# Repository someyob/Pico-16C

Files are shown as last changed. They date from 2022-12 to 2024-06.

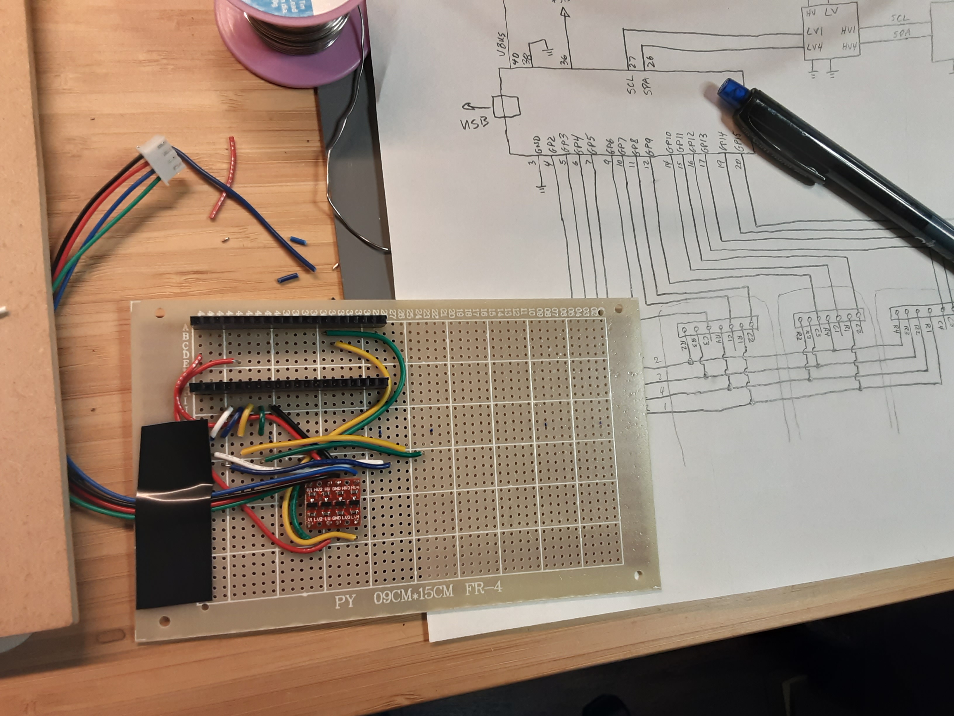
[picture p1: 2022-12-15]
pics/20221129_102227.jpg

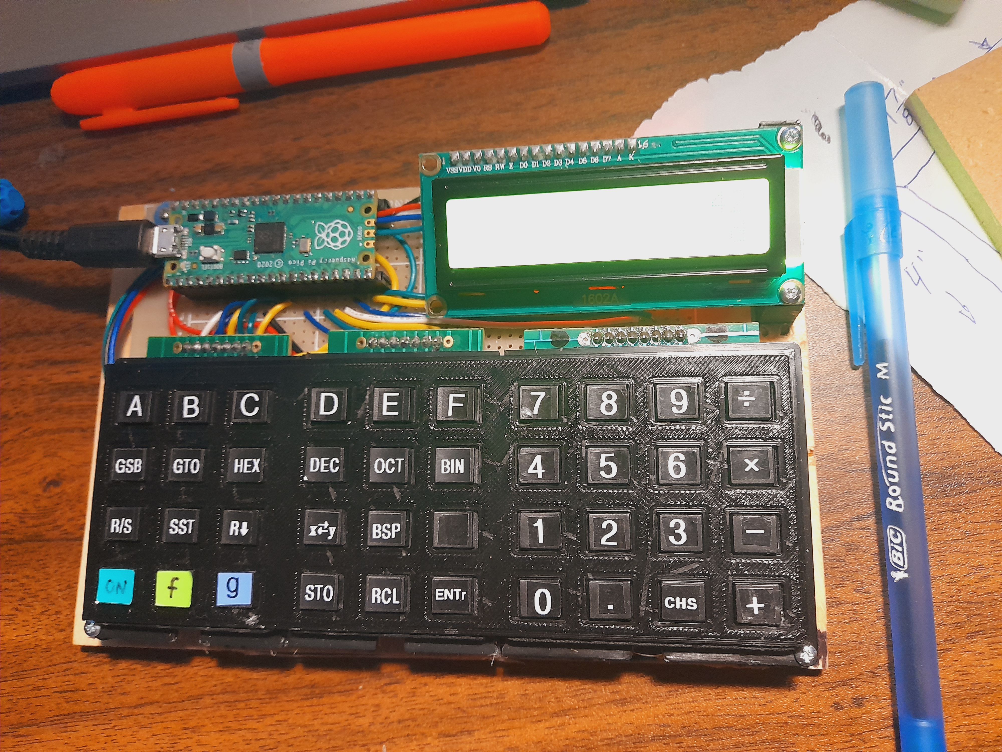
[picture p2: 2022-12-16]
pics/20221216_104609.jpg

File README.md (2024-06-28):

Hi there, while you're here, maybe check out the newer version of this project:
https://github.com/someyob/Pico16cV2

# Pico-16C

Notes for new version 0.5:
  - added floating point entry and operations.  Note that CicruitPython only uses single precision floats, so some results will seem unexpected.  < examples follow >  I may restrict the number of decimal places (for example, entering float mode by pressing f-FLOAT-{0..9,.}, where 0 to 9 represents the number of decimal points you want to work with) to 5, even though that doesn't really mitigate the issue.  Best option would be for CircuitPython to match what Python 3 is able to handle double precision floats.  Not going to get hung up on it, as I would typically not frequently use the calculator for floating point calculations.
  - Differences between Pico16C 0.5 and the HP 16C:
      - switching from an integer base to floating point will convert what's in the X register, but the opposite is not true.  Further, the conversion from integer to float simply changes the representation, not the number.  The stack is unchanged, and the word size is ignored.
      - added a 'hidden function' to allow for a 'thousands separator' (eg. 64,636) to make readability better for long numbers.  Unfortunately, separators do not work for binary and hex representations (eg. 1100 1100 0001, or FFEH AE12) due to a bug in CicruitPython as of version 8)

Wanted an HP 16C calculator, the gold standard for early programmers.  Didn't have one, too cheap to buy one off eBay, and while the new ones you can get from SwissMicro https://www.swissmicros.com/product/dm16l look great, they don't scratch my other itch, which is to play with microcontrollers and learn a new language (python).



Python is well suited to this application given a full suite of excellent string manipulation and math libraries, adafruit libraries, etc.  Execution speed is not an issue.

I was helped a lot during development with access to a couple of different software emulators out there (http://www.hp16c.org/ and https://stendec.io/ctb/rpn_prog.html), especially when I can see what's happening with the stack.  The manual https://literature.hpcalc.org/community/hp16c-oh-en.pdf was also essential reading.

An early version of this project got a mention on the Raspberry Pi blog https://www.raspberrypi.com/news/replica-hp-16c-coding-calculator/ and on Adafruit's Python on Hardware newsletter https://blog.adafruit.com/2022/10/19/icymi-python-on-microcontrollers-newsletter-ladyada-at-espressif-devcon-this-week-circuitpython-8-beta-2-and-more-circuitpython-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

display

Tools and materials used:
  - Raspberry Pi Pico
  - 1602 LCD display (w. i2c backpack)
  - breadboards and soldering iron
  - perfboard, w. 22awg wire
  - level shifter module (only using 2 out of 4 lines for i2c)
  - two 3x4 and one 4x4 aliexpress keypads (modified to jam as close together as possible)
  - 3d Printer
  - Glue gun
  - PTouch Labelmaker
  - Laser printer (for keypad overlay), highlighter pens
  - Thonny with Circuitpython 7.2.3
  
The software emulates (mimics) the basic operations of a 16C, all in Reverse Polish Notation (RPN) with the standard X, Y, Z and T registers.
What it's currently capable of:
  - integer entry in either hexadecimal, octal, decimal or binary
  - conversions between those bases
  - ordinary arithmatic (+ - / *), some bitwise operations (NOT, AND, etc)
  - stack operations x<->y, R^, Rv, LastX
  
Differences between this and a real 16C:
  - maximum 128 bit words (vs 16C 64 bit)
  - 16 character display, with eight 16 character windows, scrolling with shift-g < and > keys
  - 'Enter' key is standard size, not double lenth like a real 16C
  - Has a splash screen that gives you the current version number
  - Has a timeout feature that turns off the LCD after 5 minutes (hard coded)
  - The calculator is always 'running', ON and OFF simply turns off the display and backlight

Work to come in the near future:
  - floating point
  - more bitwise operations, 1's and 2's complement arithmetic

Work to come in the far future (if ever):
  - Programming mode

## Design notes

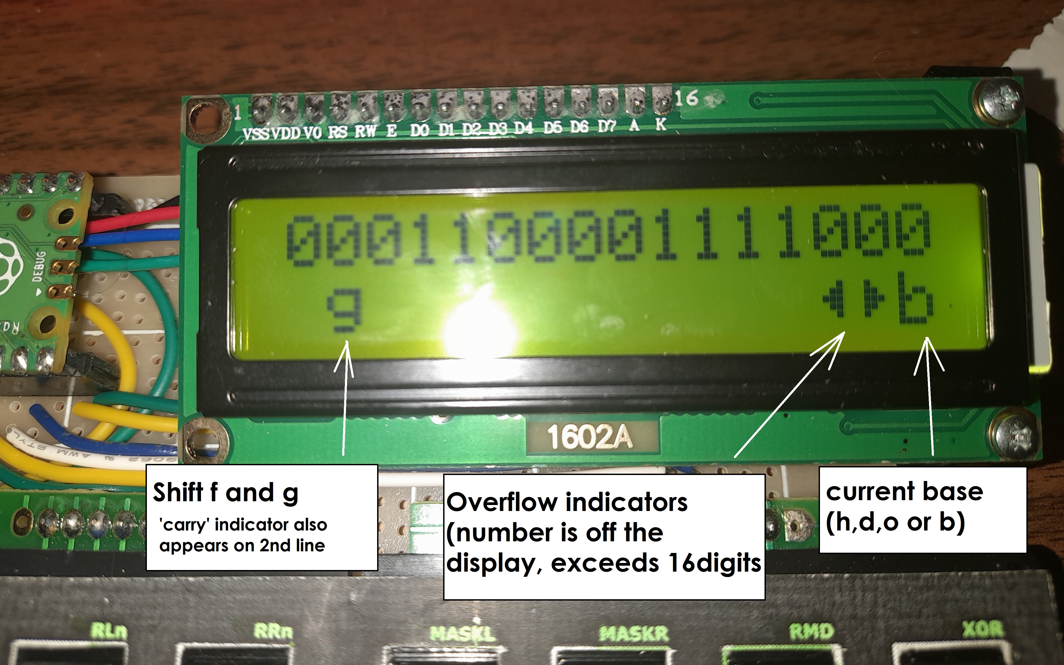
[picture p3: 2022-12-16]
pics/display.jpg

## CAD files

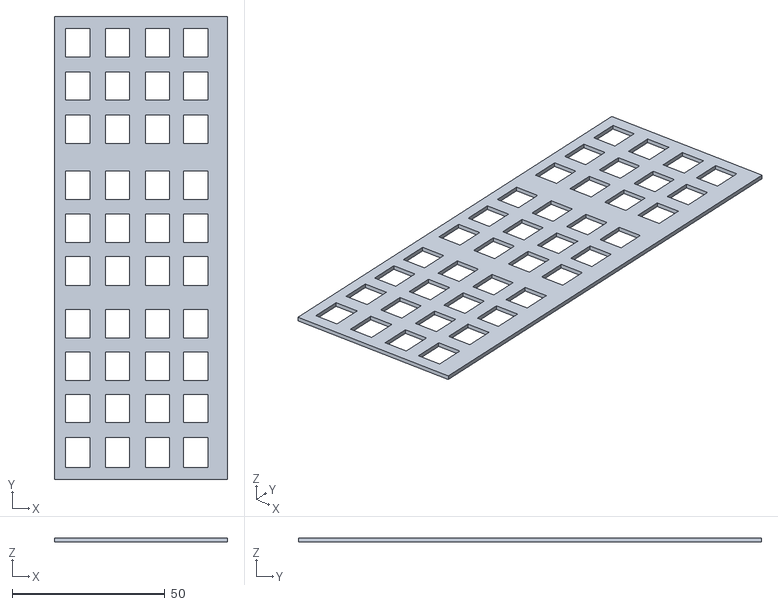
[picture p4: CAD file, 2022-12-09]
hardware/faceplate.stl
56.8 x 151.8 x 1.25

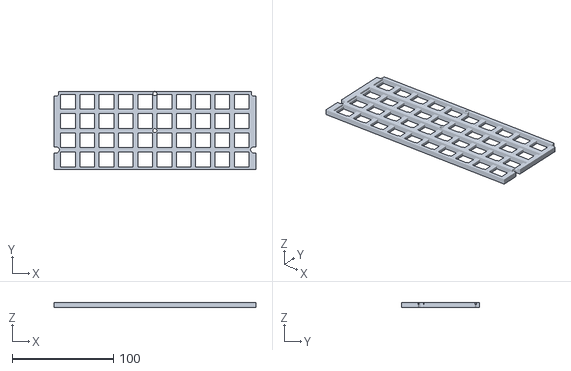
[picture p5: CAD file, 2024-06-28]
v2/3dprints/keypad.stl
199.9 x 77.6 x 4.80

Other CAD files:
hardware/faceplate.skp
hardware/spacer.skp
v2/3dprints/keypad.skp

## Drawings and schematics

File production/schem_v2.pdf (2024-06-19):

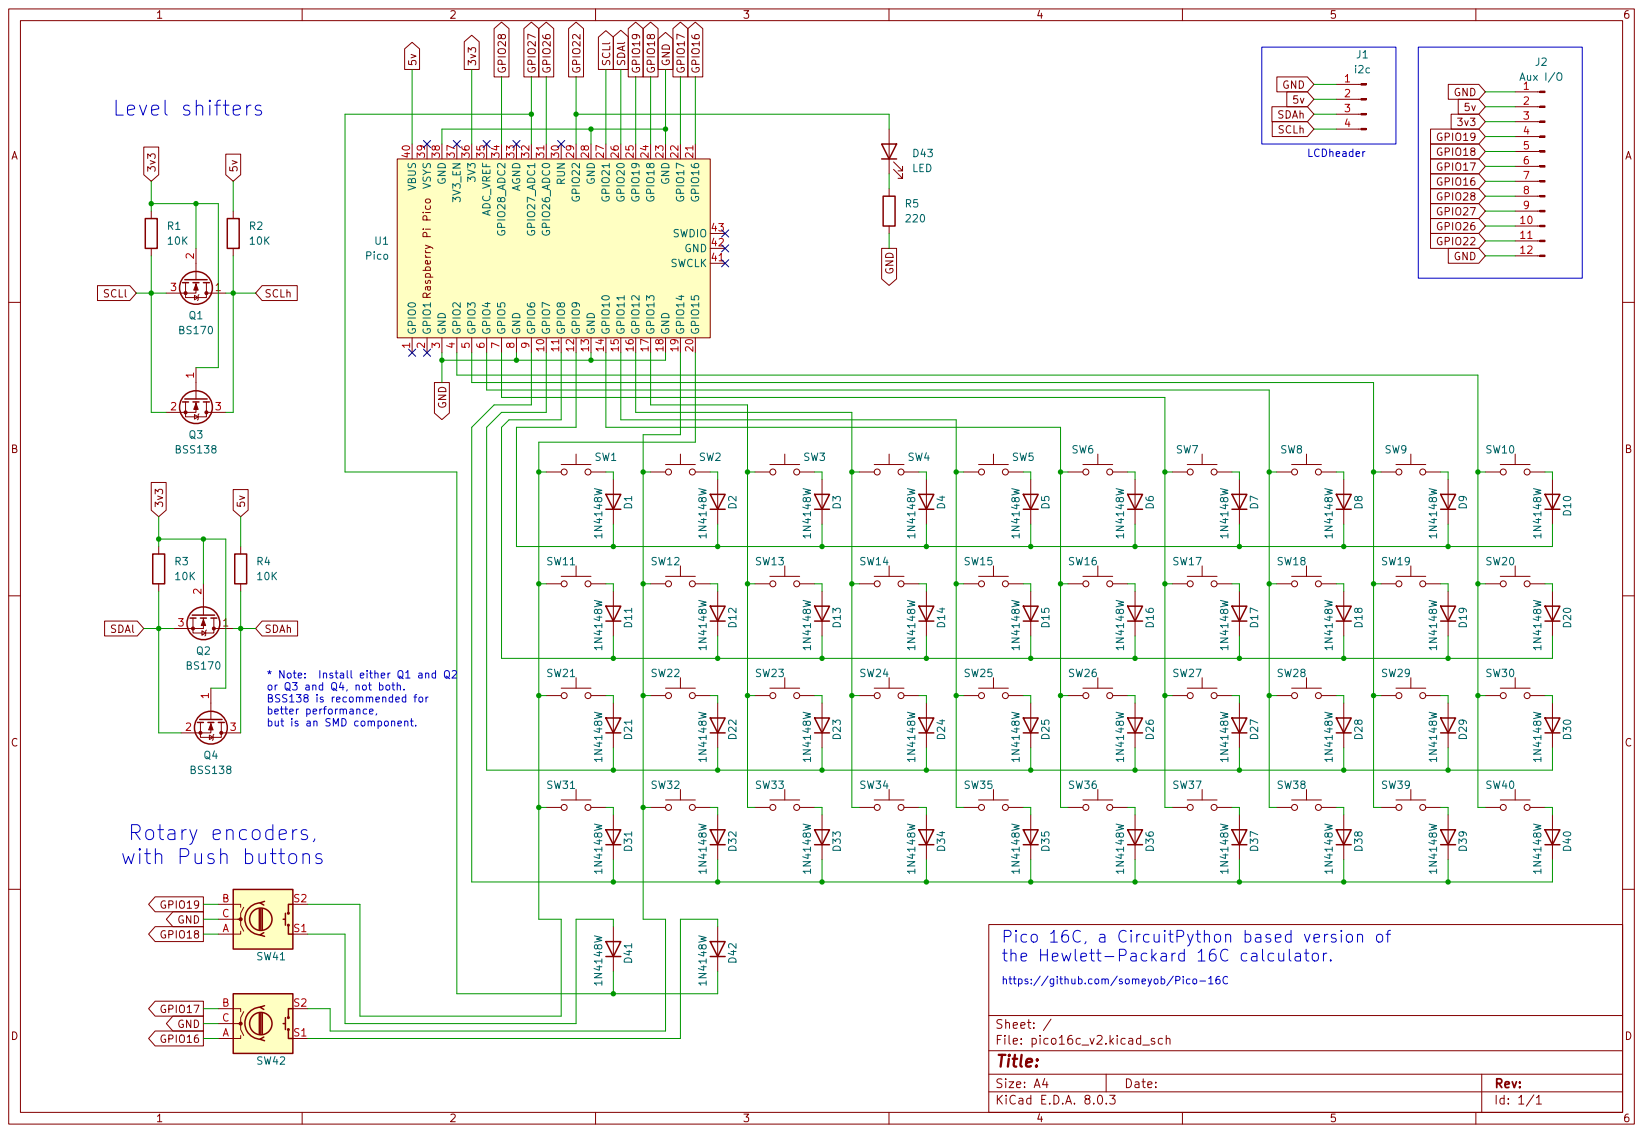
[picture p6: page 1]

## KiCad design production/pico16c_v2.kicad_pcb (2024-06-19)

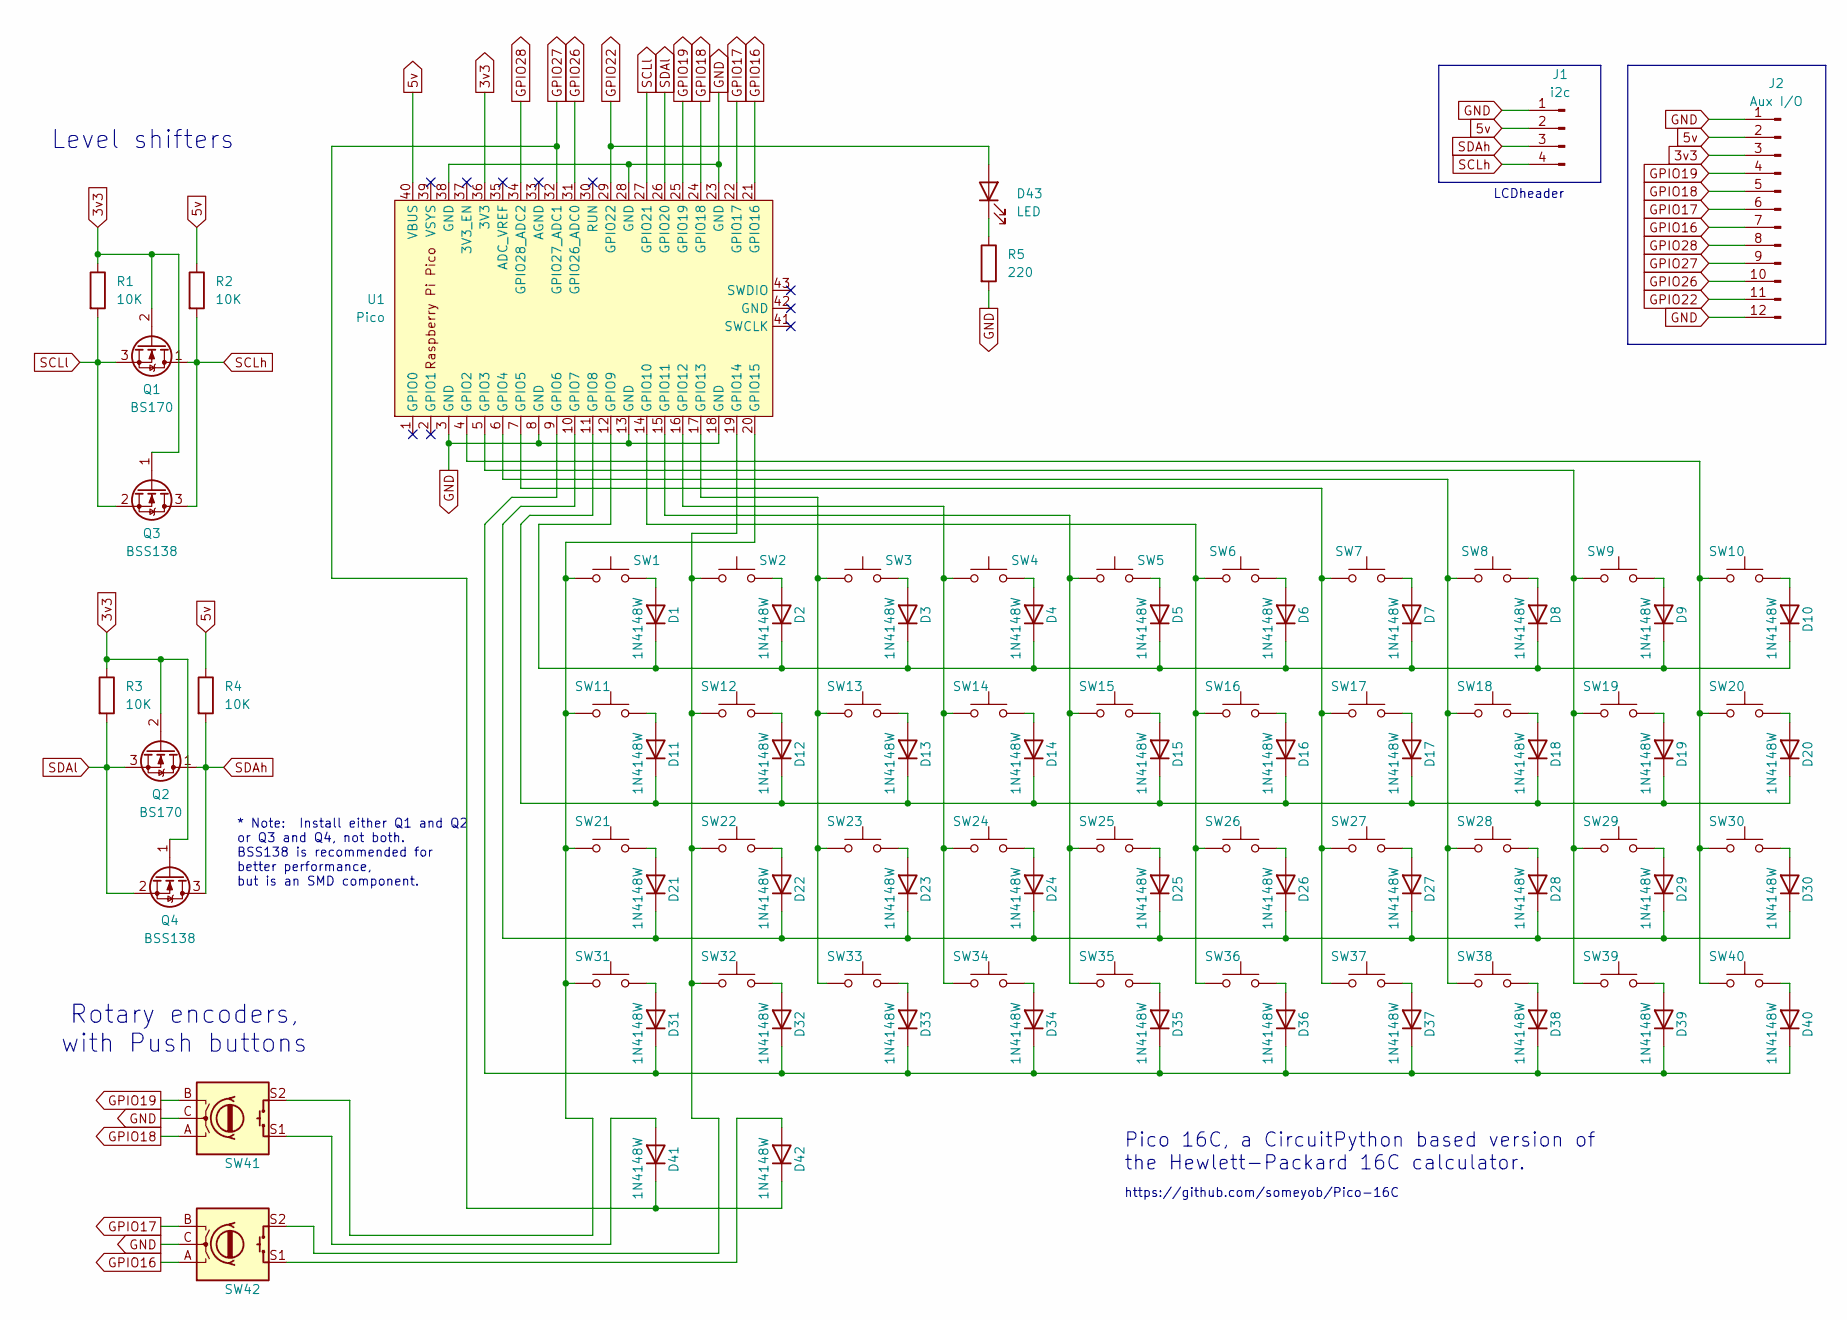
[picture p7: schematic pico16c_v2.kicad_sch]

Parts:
D1, D2, D3, D4, D5, D6, D7, D8, D9, D10, D11, D12, D13, D14, D15, D16, D17, D18, D19, D20, D21, D22, D23, D24, D25, D26, D27, D28, D29, D30, D31, D32, D33, D34, D35, D36, D37, D38, D39, D40, D41, D42: 1N4148W; D_DO-35_SOD27_P7.62mm_Horizontal
D43: LED; LED_D2.0mm_W4.0mm_H2.8mm_FlatTop
J1: i2c; PinHeader_1x04_P2.54mm_Vertical
J2: Aux I/O; PinHeader_1x12_P2.54mm_Vertical
Q1, Q2: BS170; TO-92_Inline
Q3, Q4: BSS138; SOT-23
R1, R2, R3, R4: 10K; R_Axial_DIN0207_L6.3mm_D2.5mm_P10.16mm_Horizontal
R5: 220; R_Axial_DIN0207_L6.3mm_D2.5mm_P10.16mm_Horizontal
SW1, SW2, SW3, SW4, SW5, SW6, SW7, SW8, SW9, SW10, SW11, SW12, SW13, SW14, SW15, SW16, SW17, SW18, SW19, SW20, SW21, SW22, SW23, SW24, SW25, SW26, SW27, SW28, SW29, SW30, SW31, SW32, SW33, SW34, SW35, SW36, SW37, SW38, SW39, SW40: SW_Push; SW_Cherry_MX_1.00u_PCB
SW41, SW42: Encoder_Switch; RotaryEncoder_Alps_EC11E-Switch_Vertical_H20mm
U1: Pico; RPi_Pico_SMD_TH

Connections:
3v3: J2.3, Q1.2 (G), Q2.2 (G), Q3.1 (G), Q4.1 (G), R1.1, R3.1, U1.36 (3V3)
5v: J1.2, J2.2, R2.1, R4.1, U1.40 (VBUS)
GND: J1.1, J2.1, J2.12, R5.2, SW41.C, SW42.C, U1.3 (GND), U1.8 (GND), U1.13 (GND), U1.18 (GND), U1.23 (GND), U1.28 (GND), U1.38 (GND)
GPIO16: J2.7, SW42.A, U1.21 (GPIO16)
GPIO17: J2.6, SW42.B, U1.22 (GPIO17)
GPIO18: J2.5, SW41.A, U1.24 (GPIO18)
GPIO19: J2.4, SW41.B, U1.25 (GPIO19)
GPIO22: D43.2 (A), J2.11, U1.29 (GPIO22)
GPIO26: J2.10, U1.31 (GPIO26_ADC0)
GPIO27: D41.1 (K), D42.1 (K), J2.9, U1.32 (GPIO27_ADC1)
GPIO28: J2.8, U1.34 (GPIO28_ADC2)
unnamed: D1.2 (A), SW1.1
unnamed: D1.1 (K), D2.1 (K), D3.1 (K), D4.1 (K), D5.1 (K), D6.1 (K), D7.1 (K), D8.1 (K), D9.1 (K), D10.1 (K), U1.12 (GPIO9)
unnamed: D2.2 (A), SW2.1
unnamed: D3.2 (A), SW3.1
unnamed: D4.2 (A), SW4.1
unnamed: D5.2 (A), SW5.1
unnamed: D6.2 (A), SW6.1
unnamed: D7.2 (A), SW7.1
unnamed: D8.2 (A), SW8.1
unnamed: D9.2 (A), SW9.1
unnamed: D10.2 (A), SW10.1
unnamed: D11.2 (A), SW11.1
unnamed: D11.1 (K), D12.1 (K), D13.1 (K), D14.1 (K), D15.1 (K), D16.1 (K), D17.1 (K), D18.1 (K), D19.1 (K), D20.1 (K), U1.11 (GPIO8)
unnamed: D12.2 (A), SW12.1
unnamed: D13.2 (A), SW13.1
unnamed: D14.2 (A), SW14.1
unnamed: D15.2 (A), SW15.1
unnamed: D16.2 (A), SW16.1
unnamed: D17.2 (A), SW17.1
unnamed: D18.2 (A), SW18.1
unnamed: D19.2 (A), SW19.1
unnamed: D20.2 (A), SW20.1
unnamed: D21.2 (A), SW21.1
unnamed: D21.1 (K), D22.1 (K), D23.1 (K), D24.1 (K), D25.1 (K), D26.1 (K), D27.1 (K), D28.1 (K), D29.1 (K), D30.1 (K), U1.10 (GPIO7)
unnamed: D22.2 (A), SW22.1
unnamed: D23.2 (A), SW23.1
unnamed: D24.2 (A), SW24.1
unnamed: D25.2 (A), SW25.1
unnamed: D26.2 (A), SW26.1
unnamed: D27.2 (A), SW27.1
unnamed: D28.2 (A), SW28.1
unnamed: D29.2 (A), SW29.1
unnamed: D30.2 (A), SW30.1
unnamed: D31.2 (A), SW31.1
unnamed: D31.1 (K), D32.1 (K), D33.1 (K), D34.1 (K), D35.1 (K), D36.1 (K), D37.1 (K), D38.1 (K), D39.1 (K), D40.1 (K), U1.9 (GPIO6)
unnamed: D32.2 (A), SW32.1
unnamed: D33.2 (A), SW33.1
unnamed: D34.2 (A), SW34.1
unnamed: D35.2 (A), SW35.1
unnamed: D36.2 (A), SW36.1
unnamed: D37.2 (A), SW37.1
unnamed: D38.2 (A), SW38.1
unnamed: D39.2 (A), SW39.1
unnamed: D40.2 (A), SW40.1
unnamed: D41.2 (A), SW41.S1
unnamed: D42.2 (A), SW42.S1
unnamed: D43.1 (K), R5.1
unnamed: SW10.2, SW20.2, SW30.2, SW40.2, U1.4 (GPIO2)
unnamed: SW9.2, SW19.2, SW29.2, SW39.2, U1.5 (GPIO3)
unnamed: SW8.2, SW18.2, SW28.2, SW38.2, U1.6 (GPIO4)
unnamed: SW7.2, SW17.2, SW27.2, SW37.2, U1.7 (GPIO5)
unnamed: SW6.2, SW16.2, SW26.2, SW36.2, U1.14 (GPIO10)
unnamed: SW5.2, SW15.2, SW25.2, SW35.2, U1.15 (GPIO11)
unnamed: SW4.2, SW14.2, SW24.2, SW34.2, U1.16 (GPIO12)
unnamed: SW3.2, SW13.2, SW23.2, SW33.2, U1.17 (GPIO13)
unnamed: SW2.2, SW12.2, SW22.2, SW32.2, SW42.S2, U1.19 (GPIO14)
unnamed: SW1.2, SW11.2, SW21.2, SW31.2, SW41.S2, U1.20 (GPIO15)
SCLh: J1.4, Q1.1 (D), Q3.3 (D), R2.2
SCLl: Q1.3 (S), Q3.2 (S), R1.2, U1.27 (GPIO21)
SDAh: J1.3, Q2.1 (D), Q4.3 (D), R4.2
SDAl: Q2.3 (S), Q4.2 (S), R3.2, U1.26 (GPIO20)

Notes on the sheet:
Pico 16C, a CircuitPython based version of the Hewlett-Packard 16C calculator.
https://github.com/someyob/Pico-16C
LCDheader
* Note: Install either Q1 and Q2 or Q3 and Q4, not both. BSS138 is recommended for better performance, but is an SMD component.
Rotary encoders, with Push buttons
Level shifters

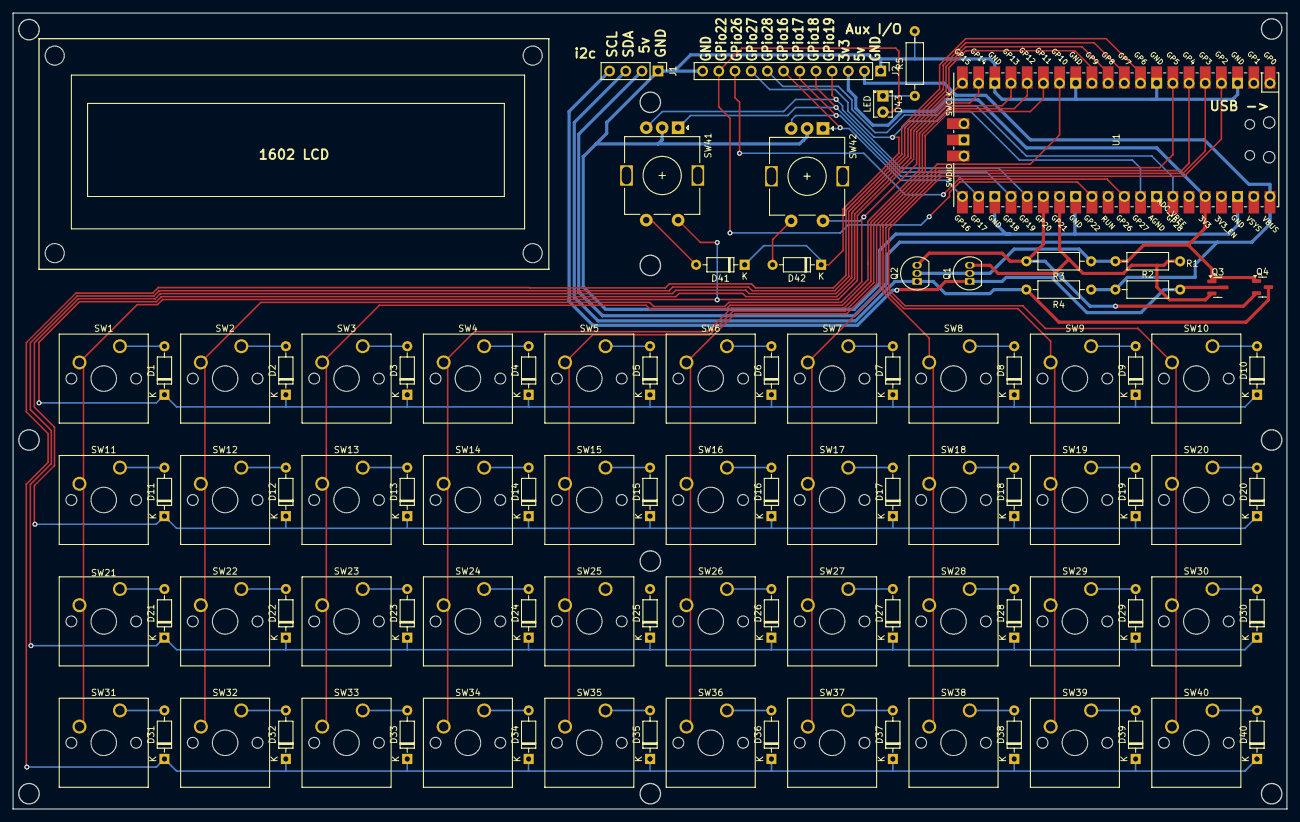
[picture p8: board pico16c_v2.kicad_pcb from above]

Board: 2 copper layers, 199.9 x 124.9 mm, 97 parts (0 on the bottom side), 72 nets.

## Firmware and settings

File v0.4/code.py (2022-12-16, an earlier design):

# to do:
# CLEAR PRGM
# CLEAR REG
# CLEAR PREFIX

import gc
import time
import board
import busio
from time import sleep, monotonic
from circuitpython_i2c_lcd import I2cLcd
from PICO_16C_keypad import *


version_string = "Pico 16C v0.4"
release_string = "13 Dec 2022"

import keypad


i2c = busio.I2C(board.GP21, board.GP20)   # SCL, SDA
# circuitpython seems to require locking the i2c bus
while i2c.try_lock():
    pass

DEFAULT_I2C_ADDR = 0x27
lcd = I2cLcd(i2c, DEFAULT_I2C_ADDR, 2, 16)

def splash():
    lcd.backlight_on()
    print(version_string)
    print(release_string)
    lcd.clear()
    lcd.putstr(version_string)
    lcd.move_to(0, 1)
    lcd.putstr(release_string)
    sleep(3)
    return

base_char = [ 'b', 'o', 'd', 'h' ]
shift_char = [' ', 'f', 'g']
float_str = 'float'
arrow_overflow_right = [ 0x00, 0x08, 0x0C, 0x0E, 0x0C, 0x08, 0x00, 0x00]
arrow_overflow_left = [ 0x00, 0x02, 0x06, 0x0E, 0x06, 0x02, 0x00, 0x00]
overflow_right_flag = 1
overflow_left_flag = 2


def display_Xreg(Xreg, base, strindex):
    # lcd.clear()
    lcd.move_to(0,0)
    OFlow = 0
    if base == BASE_STATE_BIN:
        Xstr = f'{Xreg:>16b}'
    elif base == BASE_STATE_OCT:
        Xstr = f'{Xreg:>16o}'
    elif base == BASE_STATE_DEC:
        Xstr = f'{Xreg:>16}'
    elif base == BASE_STATE_HEX:
        Xstr = f'{Xreg:>16x}'.upper()

    OFlow = 0
    if len(Xstr) > 16:
        if strindex == 0:
            Xstr = Xstr[-16:]
            OFlow += overflow_left_flag
        else:
            Xstr = Xstr[-16-strindex:-strindex]
            OFlow = overflow_right_flag + overflow_left_flag
            if len(Xstr) != 16:
                OFlow -= overflow_left_flag
            while len(Xstr) < 16:
                Xstr = ' ' + Xstr
    # print(strindex, ">", Xstr, "<")
    lcd.putstr(Xstr)
    return OFlow
    
def print_calc_modes(base, shift, carry, OFlow):
    lcd.move_to(15, 1)
    lcd.putchar(base_char[base])
    lcd.move_to(1, 1)
    lcd.putchar(shift_char[shift])
    #print(base)
    
    cust_char = base_char[base]
    if OFlow & overflow_left_flag: 
        lcd.move_to(13, 1)
        lcd.custom_char(0, arrow_overflow_left)
        lcd.putchar(chr(0))
    
    if OFlow & overflow_right_flag:  
        lcd.move_to(14, 1)
        lcd.custom_char(1, arrow_overflow_right)
        lcd.putchar(chr(1))
        
    if carry:
        lcd.move_to(11, 1)
        lcd.putchar('c')
    return
    
def display_status(calc):
    lcd.clear()
    lcd.move_to(3, 0)
    lcd.putstr(f'{calc.complement}-{calc.wordSize}-{calc.flagIndicators:0{4}b}')
    return
    
def refresh_screen(calc):
    lcd.clear()
    # time.sleep(0.1)
    
    OFlow = display_Xreg(calc.Xreg, calc.base, calc.strindex)
    print_calc_modes(calc.base, calc.shift, calc.CarryBit, OFlow)
    return

def print_status(calc):
    print("\nT ", calc.Treg)
    print("Z ", calc.Zreg)
    print("Y ", calc.Yreg)
    print("X ", calc.Xreg)
    print("  ", calc.LastX, "< LastX")
    print("Base (", base_char[calc.base], "),  Shift (", shift_char[calc.shift], ")")
    # print("strindex = ", calc.strindex)

    gc.collect()
    start_mem = gc.mem_free()
    print( "Point 1 Available memory: {} bytes".format(start_mem) ) 
    return

def main_loop():

    splash()
    lcd.clear()
    
    calculator = Calculator()
    refresh_screen(calculator)
    print_status(calculator)

    while True:
        if calculator.check_timeout() and calculator.calcstate == STATE_ON:
            lcd.backlight_off()
            # print("Timed out")
            calculator.wait_keypress()
            lcd.backlight_on()
             
        calculator.check_keypress()
        
        if (calculator.key >= 0):
            key_event = getattr(calculator, key_functions[calculator.key])
            key_event(calculator.key)             
            if calculator.calcstate == STATE_OFF:
                lcd.clear()
                lcd.backlight_off()
            else:
                lcd.backlight_on()
                if calculator.showSplash:
                    splash()
                    calculator.wait_keypress()
                    calculator.showSplash = False
                if calculator.showStatus:
                    display_status(calculator)
                    calculator.wait_keypress()
                    calculator.showStatus = False
                      
                refresh_screen(calculator)
                print_status(calculator)
    return
    

#if __name__ == "__main__":
main_loop()
